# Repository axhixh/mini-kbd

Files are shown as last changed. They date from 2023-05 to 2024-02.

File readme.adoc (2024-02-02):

= Mini Keyboard

This is my experiment with https://ergogen.xyz[Ergogen] and building
a keyboard from scratch.

I had a bunch of https://www.waveshare.com/wiki/RP2040-Zero[RP2040 Zero]
microcontrollers and Choc Mini switches to play with. Even though I am
used to 34 keys, https://github.com/axhixh/haigha-mod[Haigha Mod], and 
use it as my daily driver, I decided to build one with 36 keys because
I can do that without using diodes.

== Choc v1 vs Choc mini

While I did design this keyboard to play with Choc mini switches, I did
create a Choc v1 version since it was easy with Ergogen and I wanted to
see how to make reversible, hot-swappable PCB.

The Choc mini version of the PCB is in link:choc-mini[] and the Choc v1
version is in link:choc-v1[].

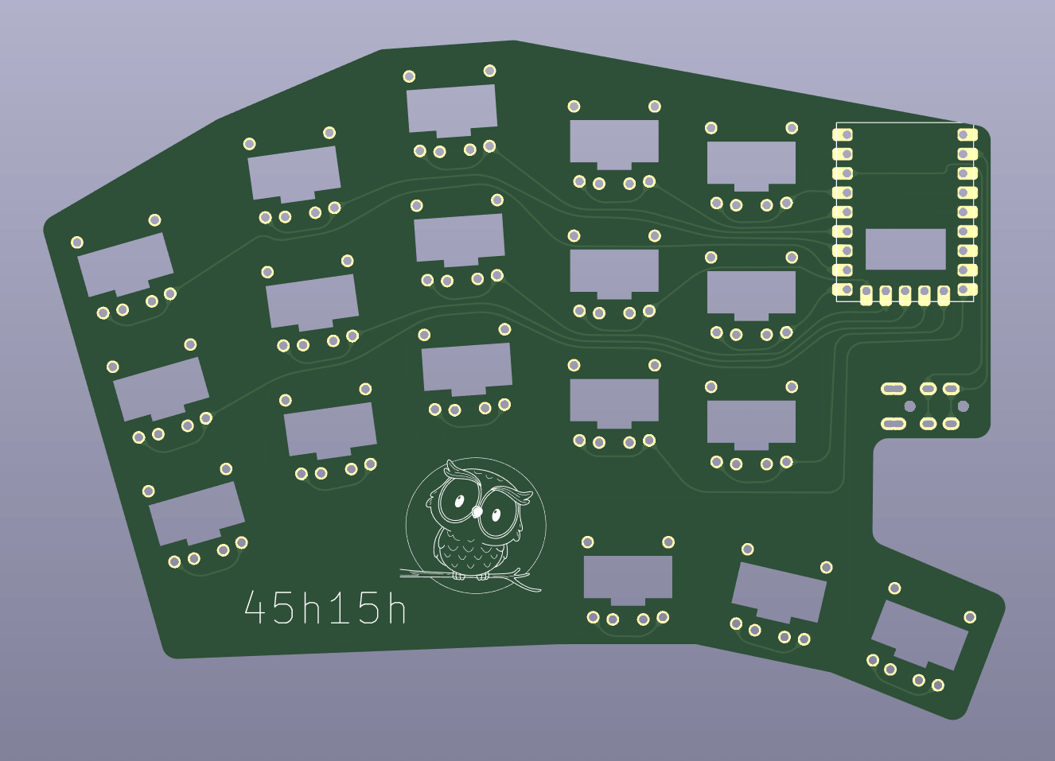
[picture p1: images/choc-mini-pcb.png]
Using Choc mini switches


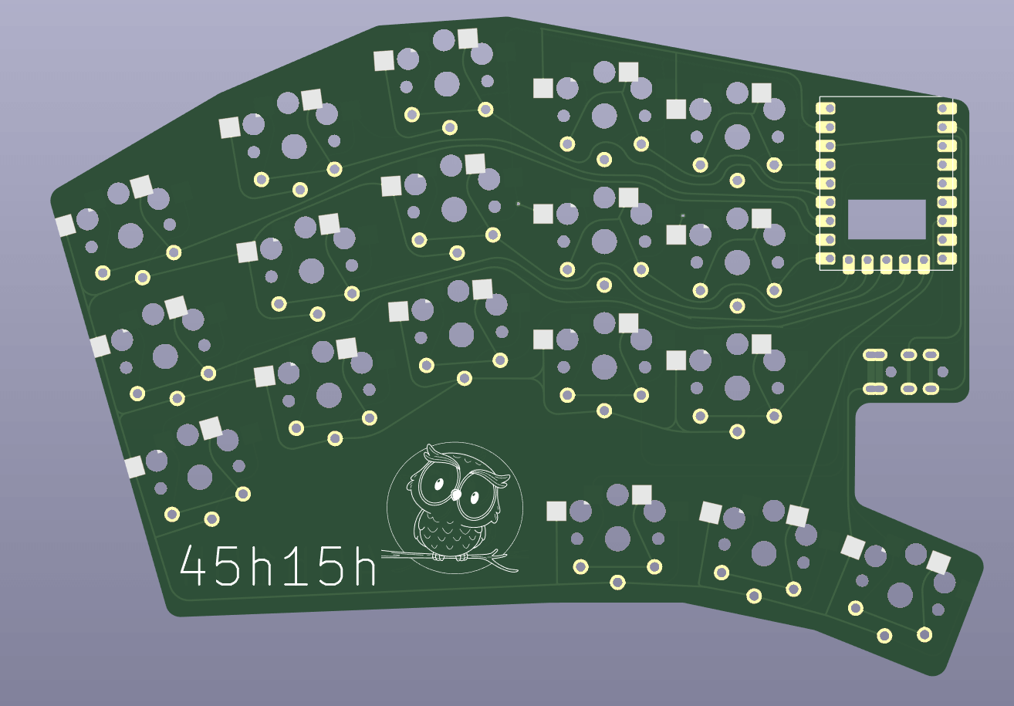
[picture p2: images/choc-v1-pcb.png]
Using Choc v1 swithes


== TRRS vs 4 pin mini DIN 

Inspired by the https://github.com/etiennecollin/wave[Wave Keyboard],
I redesigned the keyboard to use 4 pin mini DIN used by S-video to
protect the microcontroller from
https://docs.qmk.fm/#/feature_split_keyboard?id=considerations[accidentally shorting].
The layout of the key switches is the same between the different keyboards,
the connection between the two halves is the only difference.

== Releases

Please download the latest gerber files for the key switch you need from
https://github.com/axhixh/mini-kbd/releases[Releases]

Remember PCB thickness of 1.6mm for Choc mini means the pins will not pass
through the hole. I was fine with this since I use don't use a case. 

PCB for Choc mini keyboard using 4 pin mini-DIN for connecting the halves.
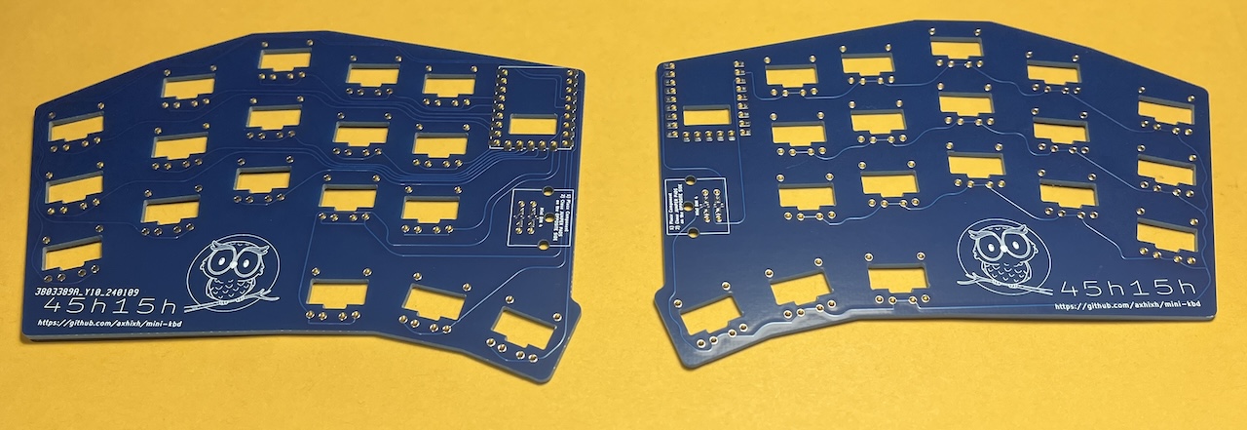
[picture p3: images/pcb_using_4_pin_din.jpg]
Photo of PCB


PCBs for Choc mini and Choc v1 using TRRS.
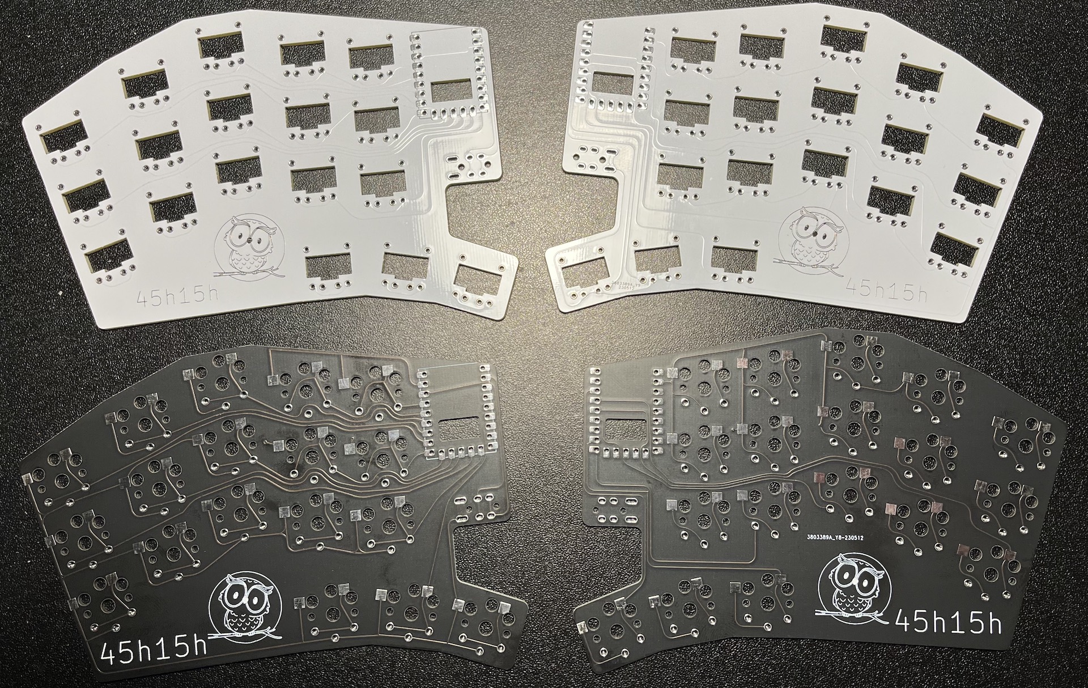
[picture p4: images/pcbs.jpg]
Photo of PCBs


Built out keyboard with Choc mini.
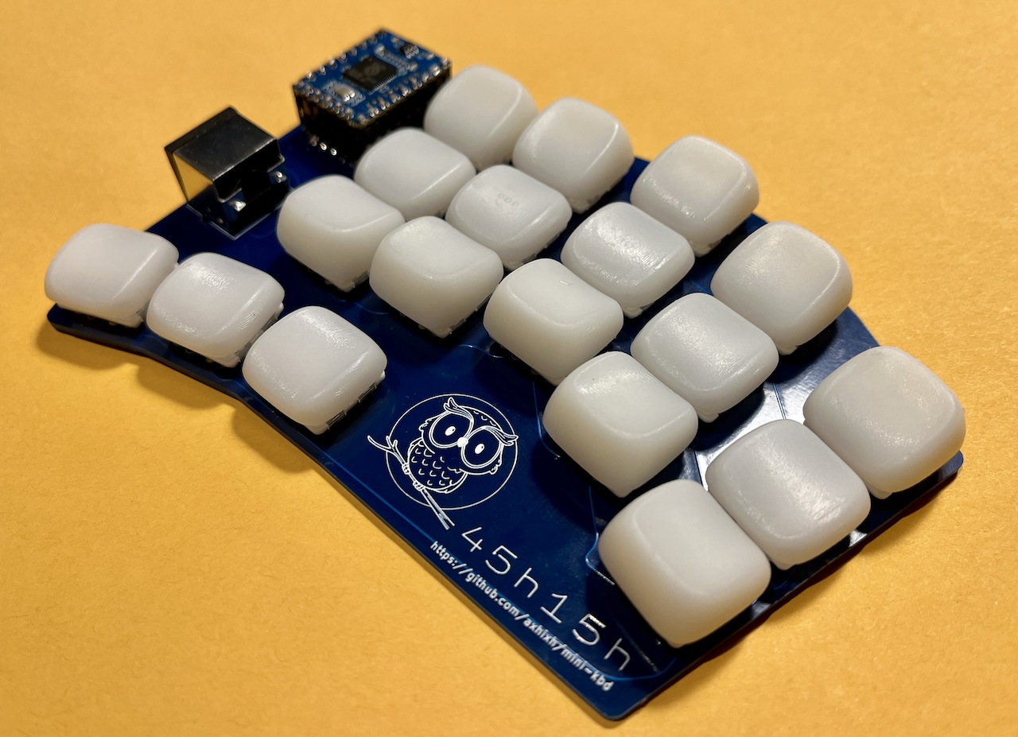
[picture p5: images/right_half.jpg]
Right Half

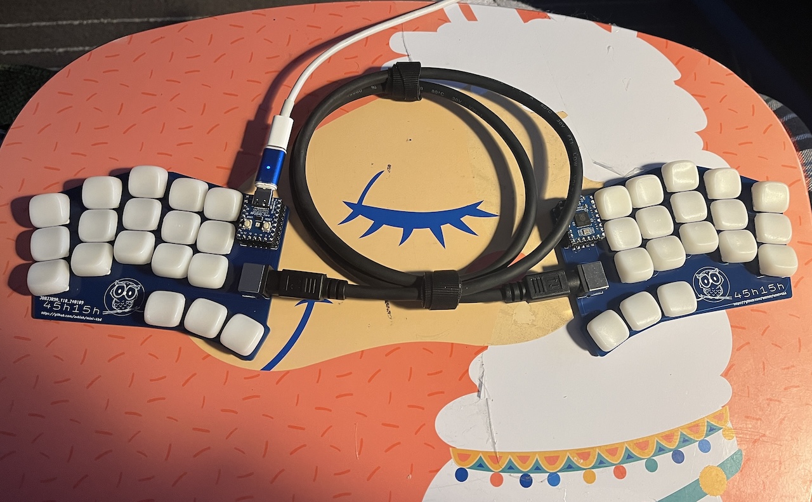
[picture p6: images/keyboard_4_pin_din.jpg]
Two halves with S-video cable

 
Built out keyboard with Choc Sunset and LDSA keycaps.
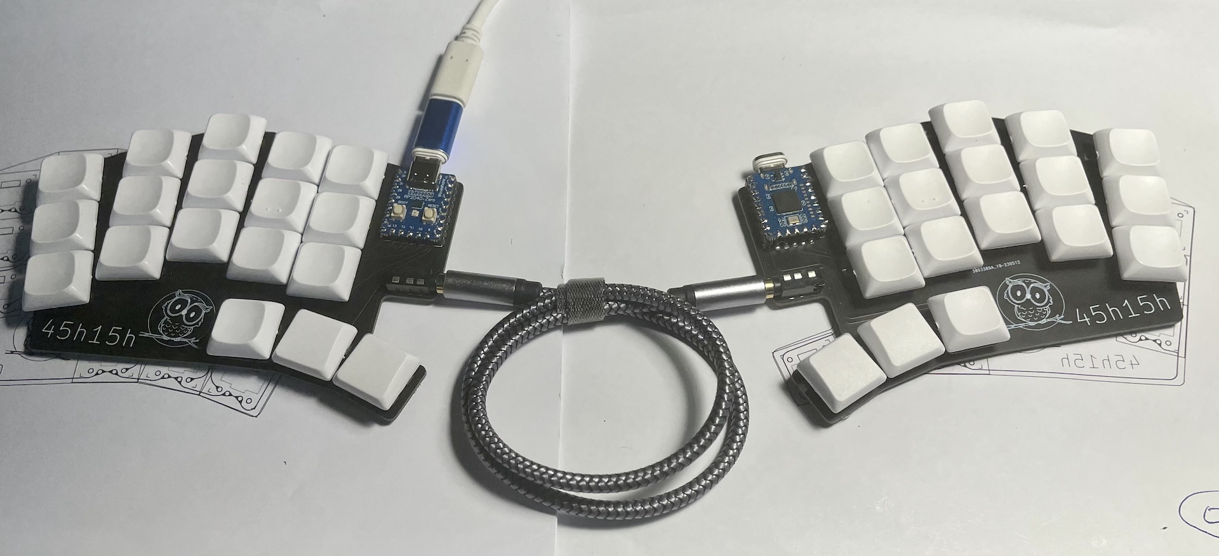
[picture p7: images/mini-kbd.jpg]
Photo of keyboard


== Firmware

The `firmware` folder contains different firmwares for the board.
Currently, it supports https://kmkfw.io[KMK] and https://docs.qmk.fm[QMK]

== References

While creating design I used https://github.com/mitxela/kicad-round-tracks[round-track]
plug-in.

The RP2040 Zero footprint is a modified version of https://github.com/CountParadox/RP2040-Zero-Kicad.
A possible improvement for future is to change it to have the origin in the center so
that rotating the footprint is easier.

The footprint for 4 pin mini-DIN is based on the one used in Wave keyboard.
I translated it to Ergogen footprint.

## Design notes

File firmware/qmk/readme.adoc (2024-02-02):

= QMK firmware for mini-kbd

This is the code necessary to use QMK on mini-kbd. Please use this
until I get it merged into QMK. This was tested with QMK with
git commit a4b124e906de105189415f061d7e64a00e2271d9.

Please copy `keyboards` to the `qmk_firmware` folder where you
have checked out the code for QMK.

Use the following command to build and flash the microcontroller.

```
    qmk flash -kb mini_kbd -km axhixh -bl uf2-split-right
    qmk flash -kb mini_kbd -km axhixh -bl uf2-split-left
```

Please press the `BOOT` button on RP2040-Zero to it in bootloader
mode. Once you have QMK you can do this by double tapping the
`reset` button if you have set one in the keymap.

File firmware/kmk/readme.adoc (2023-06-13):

= Firmware for Mini-kbd

Please visit https://kmkfw.io[KMk] to install KMK on the
the controller. When the controller remounts, please copy
the files in this folder to the root folder. Please delete
`code.py` if it exists.

Please edit `main.py` so that the `split_side` is set 
correctly for each side.

If you want to change the keymap, please edit `main.py` as
necessary.

Please use an empty `boot.py` during development. Once you
use the `boot.py` in this folder, the microcontroller will
no longer be mounted as an external drive. If you want it
to mount, then please press the outer-most, reachy, thumb
key while connecting the keyboard to the computer.

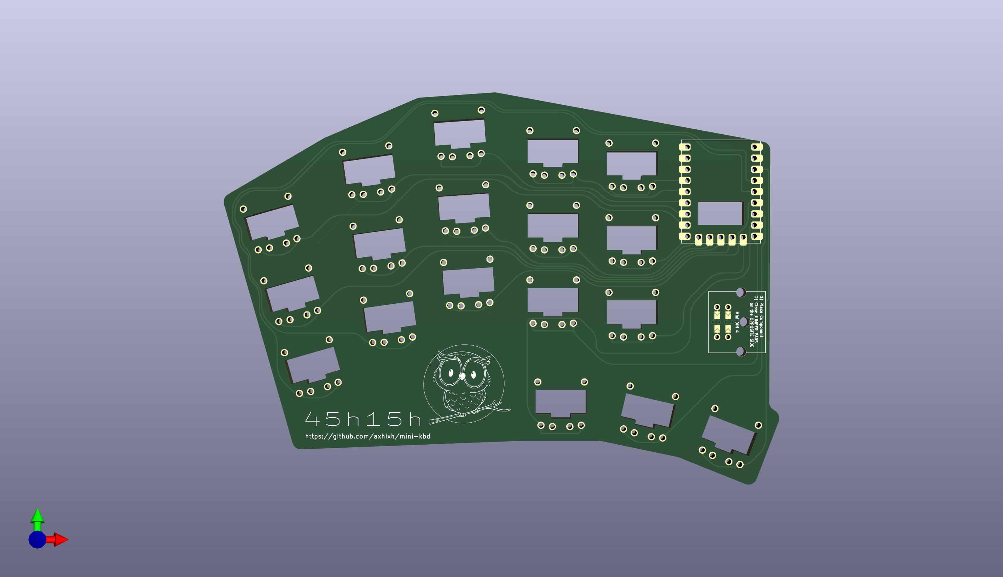
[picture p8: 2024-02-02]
images/mini-din-mini-pcb.png

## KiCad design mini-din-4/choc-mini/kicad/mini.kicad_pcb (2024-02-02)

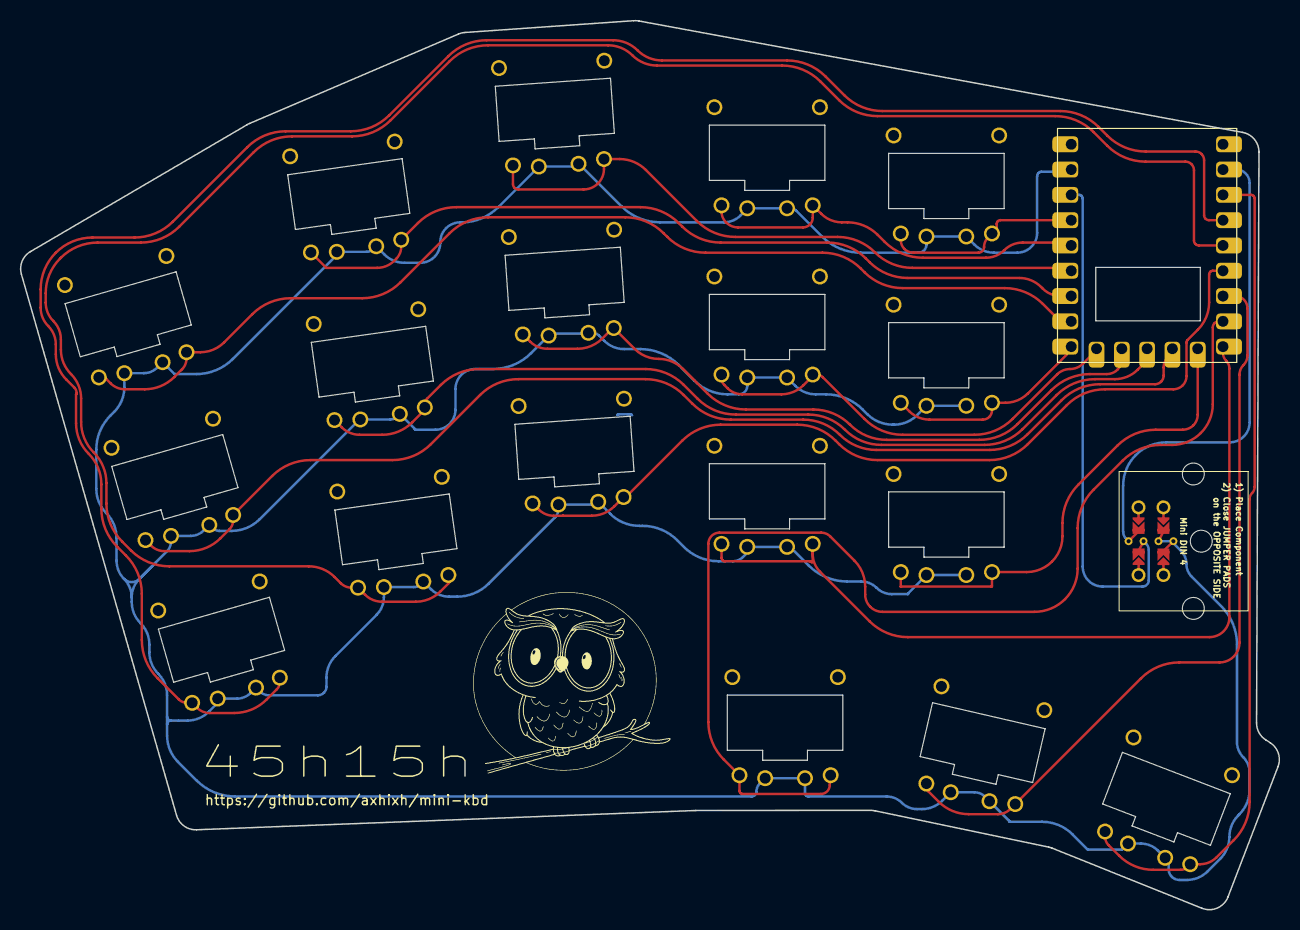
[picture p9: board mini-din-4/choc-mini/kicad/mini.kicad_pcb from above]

Board: 2 copper layers, 126.4 x 89.3 mm, 22 parts (1 on the bottom side), 21 nets.

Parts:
AdamTech-MDJ004FS1: MiniDIN4; AdamTech_MDJ-004-FS_reversible
LOGO1, LOGO2: LOGO
RP2040Zero1: RP2040-Zero
S1, S2, S3, S4, S5, S6, S7, S8, S9, S10, S11, S12, S13, S14, S15, S16, S17, S18: Kailh_PG1232

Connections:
GND: AdamTech-MDJ004FS1.3, AdamTech-MDJ004FS1.5, RP2040Zero1.20, S1.2, S2.2, S3.2, S4.2, S5.2, S6.2, S7.2, S8.2, S9.2, S10.2, S11.2, S12.2, S13.2, S14.2, S15.2, S16.2, S17.2, S18.2
GP1: AdamTech-MDJ004FS1.8, RP2040Zero1.2
GP2: RP2040Zero1.3, S18.1
GP3: RP2040Zero1.4, S1.1
GP4: RP2040Zero1.5, S4.1
GP5: RP2040Zero1.6, S7.1
GP6: RP2040Zero1.7, S17.1
GP7: RP2040Zero1.8, S16.1
GP8: RP2040Zero1.9, S10.1
GP9: RP2040Zero1.10, S13.1
GP10: RP2040Zero1.11, S2.1
GP11: RP2040Zero1.12, S5.1
GP12: RP2040Zero1.13, S8.1
GP13: RP2040Zero1.14, S11.1
GP14: RP2040Zero1.15, S14.1
GP15: RP2040Zero1.16, S3.1
GP26: RP2040Zero1.17, S6.1
GP27: RP2040Zero1.18, S9.1
GP28: RP2040Zero1.22, S12.1
GP29: RP2040Zero1.23, S15.1
P3V3: AdamTech-MDJ004FS1.6, RP2040Zero1.21

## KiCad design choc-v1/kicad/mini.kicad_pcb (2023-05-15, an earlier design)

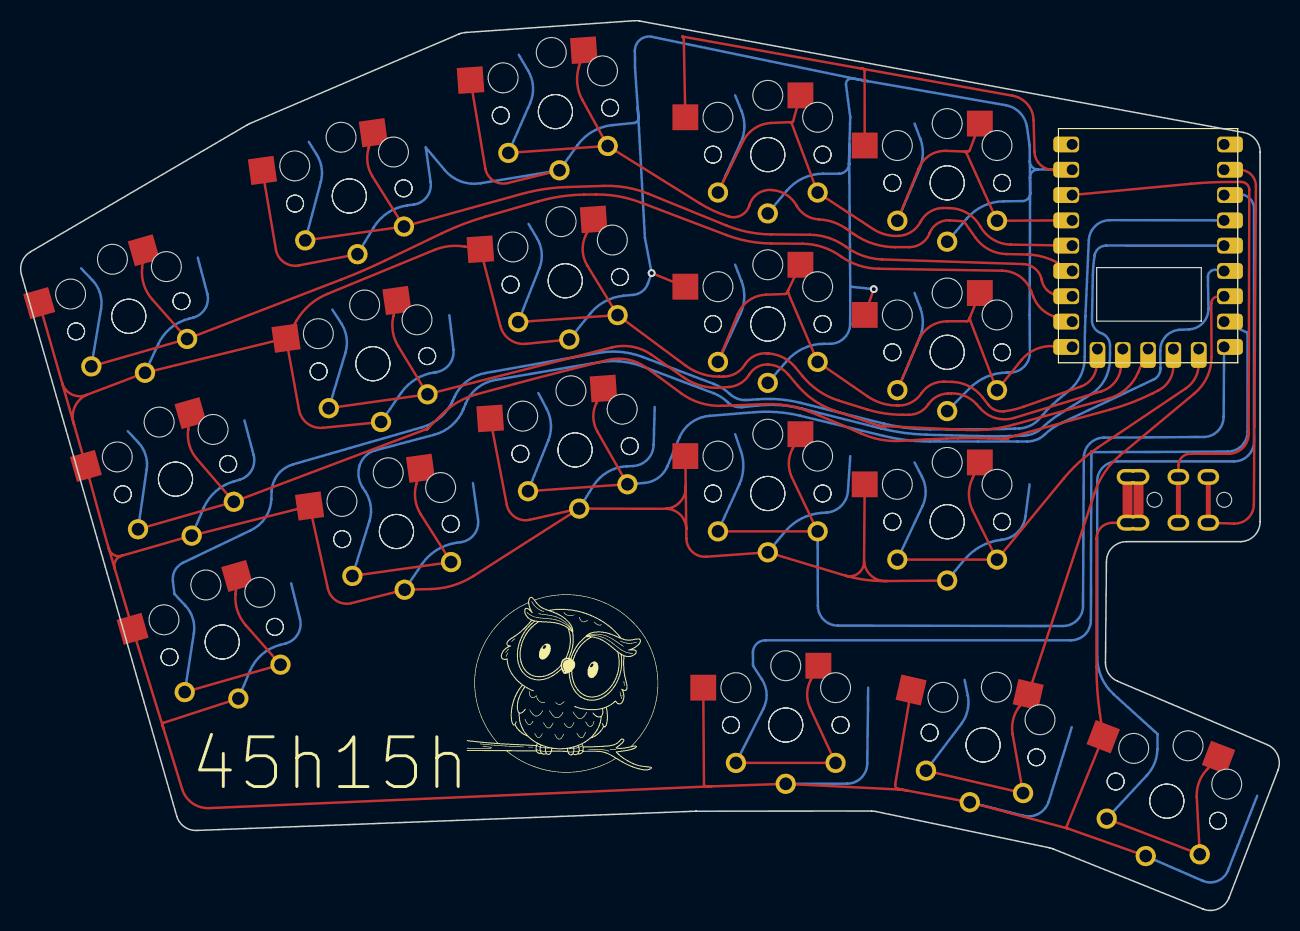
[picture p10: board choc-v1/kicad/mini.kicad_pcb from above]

Board: 2 copper layers, 126.3 x 89.3 mm, 38 parts (0 on the bottom side), 21 nets.

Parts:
RP2040Zero1: RP2040-Zero
S1, S2, S3, S4, S5, S6, S7, S8, S9, S10, S11, S12, S13, S14, S15, S16, S17, S18, S19, S20, S21, S22, S23, S24, S25, S26, S27, S28, S29, S30, S31, S32, S33, S34, S35, S36: PG1350
TRRS1: TRRS-PJ-320A-dual

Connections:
GND: RP2040Zero1.20, S1.2, S2.2, S3.2, S4.2, S5.2, S6.2, S7.2, S8.2, S9.2, S10.2, S11.2, S12.2, S13.2, S14.2, S15.2, S16.2, S17.2, S18.2, S19.2, S20.2, S21.2, S22.2, S23.2, S24.2, S25.2, S26.2, S27.2, S28.2, S29.2, S30.2, S31.2, S32.2, S33.2, S34.2, S35.2, S36.2, TRRS1.1, TRRS1.2
GP1: RP2040Zero1.2, TRRS1.4
GP2: RP2040Zero1.3, S18.1, S36.1
GP3: RP2040Zero1.4, S1.1, S19.1
GP4: RP2040Zero1.5, S4.1, S22.1
GP5: RP2040Zero1.6, S7.1, S25.1
GP6: RP2040Zero1.7, S17.1, S35.1
GP7: RP2040Zero1.8, S16.1, S34.1
GP8: RP2040Zero1.9, S10.1, S28.1
GP9: RP2040Zero1.10, S13.1, S31.1
GP10: RP2040Zero1.11, S2.1, S20.1
GP11: RP2040Zero1.12, S5.1, S23.1
GP12: RP2040Zero1.13, S8.1, S26.1
GP13: RP2040Zero1.14, S11.1, S29.1
GP14: RP2040Zero1.15, S14.1, S32.1
GP15: RP2040Zero1.16, S3.1, S21.1
GP26: RP2040Zero1.17, S6.1, S24.1
GP27: RP2040Zero1.18, S9.1, S27.1
GP28: RP2040Zero1.22, S12.1, S30.1
GP29: RP2040Zero1.23, S15.1, S33.1
P3V3: RP2040Zero1.21, TRRS1.3

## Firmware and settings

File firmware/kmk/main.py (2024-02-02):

import board

from kb import KMKKeyboard

from kmk.keys import KC
from kmk.extensions.media_keys import MediaKeys
from kmk.modules.capsword import CapsWord
from kmk.modules.combos import Chord, Combos
from kmk.modules.holdtap import HoldTap
from kmk.modules.layers import Layers
from kmk.modules.mouse_keys import MouseKeys
from kmk.modules.oneshot import OneShot
from kmk.modules.split import Split, SplitSide

keyboard = KMKKeyboard()
keyboard.modules.append(Layers())

# comment one of these on each side
#split_side = SplitSide.LEFT
split_side = SplitSide.RIGHT
split = Split(
    data_pin=board.GP1, 
    uart_flip=True,
    use_pio=True,
    split_side=split_side)
keyboard.modules.append(split)

keyboard.modules.append(HoldTap())
keyboard.modules.append(MouseKeys()) 
keyboard.modules.append(CapsWord()) 

oneshot = OneShot()
keyboard.modules.append(oneshot)

OS_LCTL = KC.OS(KC.LCTL, tap_time=None)
OS_LSFT = KC.OS(KC.LSFT, tap_time=None)
OS_LGUI = KC.OS(KC.LGUI, tap_time=None)
OS_LALT = KC.OS(KC.LALT, tap_time=None)

OS_LCTL_LSFT = KC.OS(KC.LCTL(OS_LSFT), tap_time=None)
OS_LCTL_LALT = KC.OS(KC.LCTL(OS_LALT), tap_time=None)
OS_LCTL_LGUI = KC.OS(KC.LCTL(OS_LGUI), tap_time=None)
OS_LSFT_LALT = KC.OS(KC.LSFT(OS_LALT), tap_time=None)
OS_LSFT_LGUI = KC.OS(KC.LSFT(OS_LGUI), tap_time=None)
OS_LALT_LGUI = KC.OS(KC.LALT(OS_LGUI), tap_time=None)

OS_LCTL_LSFT_LGUI = KC.OS(KC.LCTL(KC.LSFT(OS_LGUI)), tap_time=None)
OS_LCTL_LSFT_LALT = KC.OS(KC.LCTL(KC.LSFT(OS_LALT)), tap_time=None)
OS_LCTL_LALT_LGUI = KC.OS(KC.LCTL(KC.LALT(OS_LGUI)), tap_time=None)
OS_LSFT_LALT_LGUI = KC.OS(KC.LSFT(KC.LALT(OS_LGUI)), tap_time=None)

OS_LCTL_LSFT_LALT_LGUI = KC.OS(KC.LCTL(KC.LSFT(KC.LALT(OS_LGUI))), tap_time=None)

combos = Combos()
keyboard.modules.append(combos)

combos.combos = [
    Chord((OS_LCTL, OS_LSFT), OS_LCTL_LSFT, timeout=1000),
    Chord((OS_LCTL, OS_LALT), OS_LCTL_LALT, timeout=1000),
    Chord((OS_LCTL, OS_LGUI), OS_LCTL_LGUI, timeout=1000),
    Chord((OS_LSFT, OS_LALT), OS_LSFT_LALT, timeout=1000),
    Chord((OS_LSFT, OS_LGUI), OS_LSFT_LGUI, timeout=1000),
    Chord((OS_LALT, OS_LGUI), OS_LALT_LGUI, timeout=1000),

    Chord((OS_LCTL, OS_LSFT, OS_LGUI), OS_LCTL_LSFT_LGUI, timeout=1000),
    Chord((OS_LCTL, OS_LSFT, OS_LALT), OS_LCTL_LSFT_LALT, timeout=1000),
    Chord((OS_LCTL, OS_LALT, OS_LGUI), OS_LCTL_LALT_LGUI, timeout=1000),
    Chord((OS_LSFT, OS_LALT, OS_LGUI), OS_LSFT_LALT_LGUI, timeout=1000),

   Chord((OS_LCTL, OS_LSFT, OS_LALT, OS_LGUI), OS_LCTL_LSFT_LALT_LGUI, timeout=1000),
]

keyboard.extensions.append(MediaKeys())

# layer taps
L1_TAB = KC.LT(1, KC.TAB)
L2_SPC = KC.LT(2, KC.SPC)
L3_ESC = KC.LT(3, KC.ESC)

# shortcuts
LOCK    = KC.LCTRL(KC.LGUI(KC.Q))

SSHOT     = KC.LGUI(KC.LSFT(KC.N4)) # screenshot
PRV_TAB   = KC.LGUI(KC.LSFT(KC.LBRC))
NXT_TAB   = KC.LGUI(KC.LSFT(KC.RBRC))
PRV_WND   = KC.LGUI(KC.GRV)
ZOOM_P    = KC.LGUI(KC.EQL)
ZOOM_M    = KC.LGUI(KC.MINS)

# aerospace window manager shortcuts
WM_UP = KC.LALT(KC.UP)
WM_DOWN = KC.LALT(KC.DOWN)
WM_LEFT = KC.LALT(KC.LEFT)
WM_RIGHT = KC.LALT(KC.RIGHT)

WM_SRVC = KC.LSFT(KC.LALT(KC.SCLN)) 
WM_JOIN = KC.LSFT(KC.LALT(KC.SLSH)) 
WM_NEXT = KC.LALT(KC.TAB)
WM_NEXT_MNTR = KC.LSFT(KC.LALT(KC.TAB))
WM_INC = KC.LSFT(KC.LALT(KC.EQL))
WM_DEC = KC.LSFT(KC.LALT(KC.MINS))
WM_STACK = KC.LCTRL(KC.LALT(KC.COMM))
WM_TILE = KC.LCTRL(KC.LALT(KC.SLSH))

WM_0 = KC.LCTRL(KC.LALT(KC.N0))
WM_1 = KC.LCTRL(KC.LALT(KC.N1))
WM_2 = KC.LCTRL(KC.LALT(KC.N2))
WM_3 = KC.LCTRL(KC.LALT(KC.N3))
WM_4 = KC.LCTRL(KC.LALT(KC.N4))
WM_5 = KC.LCTRL(KC.LALT(KC.N5))
WM_6 = KC.LCTRL(KC.LALT(KC.N6))
WM_7 = KC.LCTRL(KC.LALT(KC.N7))

keyboard.keymap = [
    [
      KC.Q, KC.W, KC.F, KC.P, KC.B, KC.J, KC.L, KC.U, KC.Y, KC.QUOT,
      KC.A, KC.R, KC.S, KC.T, KC.G, KC.M, KC.N, KC.E, KC.I, KC.O,
      KC.Z, KC.X, KC.C, KC.D, KC.V, KC.K, KC.H, KC.COMM, KC.DOT, KC.SLSH,
      OS_LGUI, KC.ENT, L1_TAB, L3_ESC, L2_SPC, OS_LSFT
    ],
    [
      LOCK, KC.MB_RMB, KC.MS_UP, KC.MB_LMB, KC.MW_UP, KC.PGUP, KC.HOME, KC.UP, KC.END, KC.DEL,
      KC.HYPR, KC.MS_LT, KC.MS_DN, KC.MS_RT, KC.MW_DN, KC.PGDN, KC.LEFT, KC.DOWN, KC.RGHT, KC.BSPC,
      ZOOM_P, ZOOM_M, OS_LALT, OS_LCTL, KC.CW, PRV_TAB, NXT_TAB, PRV_WND, KC.INS, SSHOT,
      KC.RESET, KC.NO, KC.TRNS, KC.VOLU, KC.MUTE, KC.VOLD
    ],
    [
      KC.EXLM, KC.AT, KC.HASH, KC.DLR, KC.PERC, KC.PLUS, KC.EQL, KC.ASTR, KC.UNDS, KC.TILD,
      KC.N1, KC.N2, KC.N3, KC.N4, KC.N5, KC.LBRC, KC.LCBR, KC.LPRN, KC.MINS, KC.GRV,
      KC.N6, KC.N7, KC.N8, KC.N9, KC.N0, KC.RBRC, KC.RCBR, KC.RPRN, KC.PIPE, KC.BSLS,
      KC.AMPR, KC.SCLN, KC.COLN, KC.NO, KC.TRNS, KC.RESET
    ],
    [
      KC.F1, KC.F2, KC.F3, KC.F4, WM_SRVC, WM_UP, WM_0, WM_1, WM_2, WM_3, 
      KC.F5, KC.F6, KC.F7, KC.F8, WM_JOIN, WM_DOWN, WM_4, WM_5, WM_6, WM_7,
      KC.F9, KC.F10, KC.F11, KC.F12, WM_NEXT, WM_LEFT, WM_RIGHT, WM_INC, WM_DEC, WM_NEXT_MNTR,
      WM_STACK, WM_TILE, KC.LSFT, KC.TRNS, KC.NO, KC.RESET
    ]
  ]

if __name__ == "__main__":
    keyboard.go()

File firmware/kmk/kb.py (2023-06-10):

import board

from kmk.kmk_keyboard import KMKKeyboard as _KMKKeyboard
from kmk.scanners.keypad import KeysScanner

_KEY_CFG_LEFT = [
    board.GP15, board.GP26, board.GP27, board.GP28, board.GP29,
    board.GP10, board.GP11, board.GP12, board.GP13, board.GP14,
    board.GP3,  board.GP4,  board.GP5,  board.GP8,  board.GP9,
    board.GP7,  board.GP6,  board.GP2  
]

class KMKKeyboard(_KMKKeyboard):
    def __init__(self):
        self.matrix = KeysScanner(_KEY_CFG_LEFT)
        
        # fmt: off
        self.coord_mapping = [
         0,  1,  2,  3,  4,  22, 21, 20, 19, 18,
         5,  6,  7,  8,  9,  27, 26, 25, 24, 23,
        10, 11, 12, 13, 14,  32, 31, 30, 29, 28,
                15, 16, 17,  35, 34, 33,
        ]

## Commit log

2023-05-15 release 1 of mini
    [mini-B_Cu.gbr, mini-B_Mask.gbr, mini-B_Paste.gbr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]
2023-05-15 info about gerber files
2023-05-15 ignore kicad backups
2023-05-15 add more clearance to 3.3v route
    [mini-B_Cu.gbr, mini-B_Mask.gbr, mini-B_Paste.gbr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]
2023-05-15 add pcb images
2023-05-22 ignore release gerber zip files
2023-06-11 fix media keys for kmk
    [main.py]
2023-06-13 stop mounting the microcontroller as a drive
2023-08-15 make reset switch each layer consistent
2024-01-07 footprint for 4pin mini din socket
2024-01-08 support footprint to add custom text (#3)
    * add footprint for text
    * added comment about changes
2024-02-02 add keyboard based on mini 4 pin DIN (#4)
    * add new keyboard based on mini din connector
    * updated with photos of keyboard of 4 pin mini-din
    * keymap updated to support aerospace window manager
    * updated license
    * add qmk files
    [mini-B_Cu.gbr, mini-B_Mask.gbr, mini-B_Paste.gbr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]
